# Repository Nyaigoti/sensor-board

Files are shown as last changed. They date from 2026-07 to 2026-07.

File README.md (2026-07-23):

# Custom IoT PCB with ESP32-C3-02 and TP4056 Li-ion Charger

This project involves the design and development of a custom PCB for an IoT application powered by the ESP32-C3-02 SoC. The board includes integrated power management features using the TP4056 Li-ion battery charger IC, enabling efficient and safe charging of a single-cell Li-ion battery.

### Key Features

- **Microcontroller**: ESP32-C3-02 SoC for Wi-Fi and BLE connectivity.
- **Power Management**: TP4056 IC for single-cell Li-ion battery charging with thermal regulation.
- **Battery Protection**: Integrated under-voltage lockout and trickle charging.
- **Sensors and Modules**:
  - BME280 for temperature, humidity, and pressure sensing.
  - Ambient light and sound sensors.
  - Mini SD card reader for data storage.
  - Flash memory for additional storage.
- **Display**: I2C OLED for real-time data visualization.
- **Power Inputs**:
  - USB-C connector for charging and data transfer.
  - LiPo battery connector with onboard charging circuitry.
- **Indicators**: LED indicators for charge status (charging and full).

### Design Highlights

1. **Power Supply Integration**:
   - USB-C provides power for both charging and system operation.
   - TP4056 handles battery charging and protection.
   - Power supplied to the ESP32-C3-02 is regulated for stability.

2. **Modular Architecture**:
   - Supports various sensors and peripherals for IoT applications.
   - Expandable via additional I2C devices.

3. **Safe and Efficient Charging**:
   - Programmable charging current using an external resistor.
   - Automatic charge termination and battery protection.

4. **Compact and Reliable Layout**:
   - Optimized PCB traces for minimal power loss.
   - Thermal management for the TP4056 and other components.

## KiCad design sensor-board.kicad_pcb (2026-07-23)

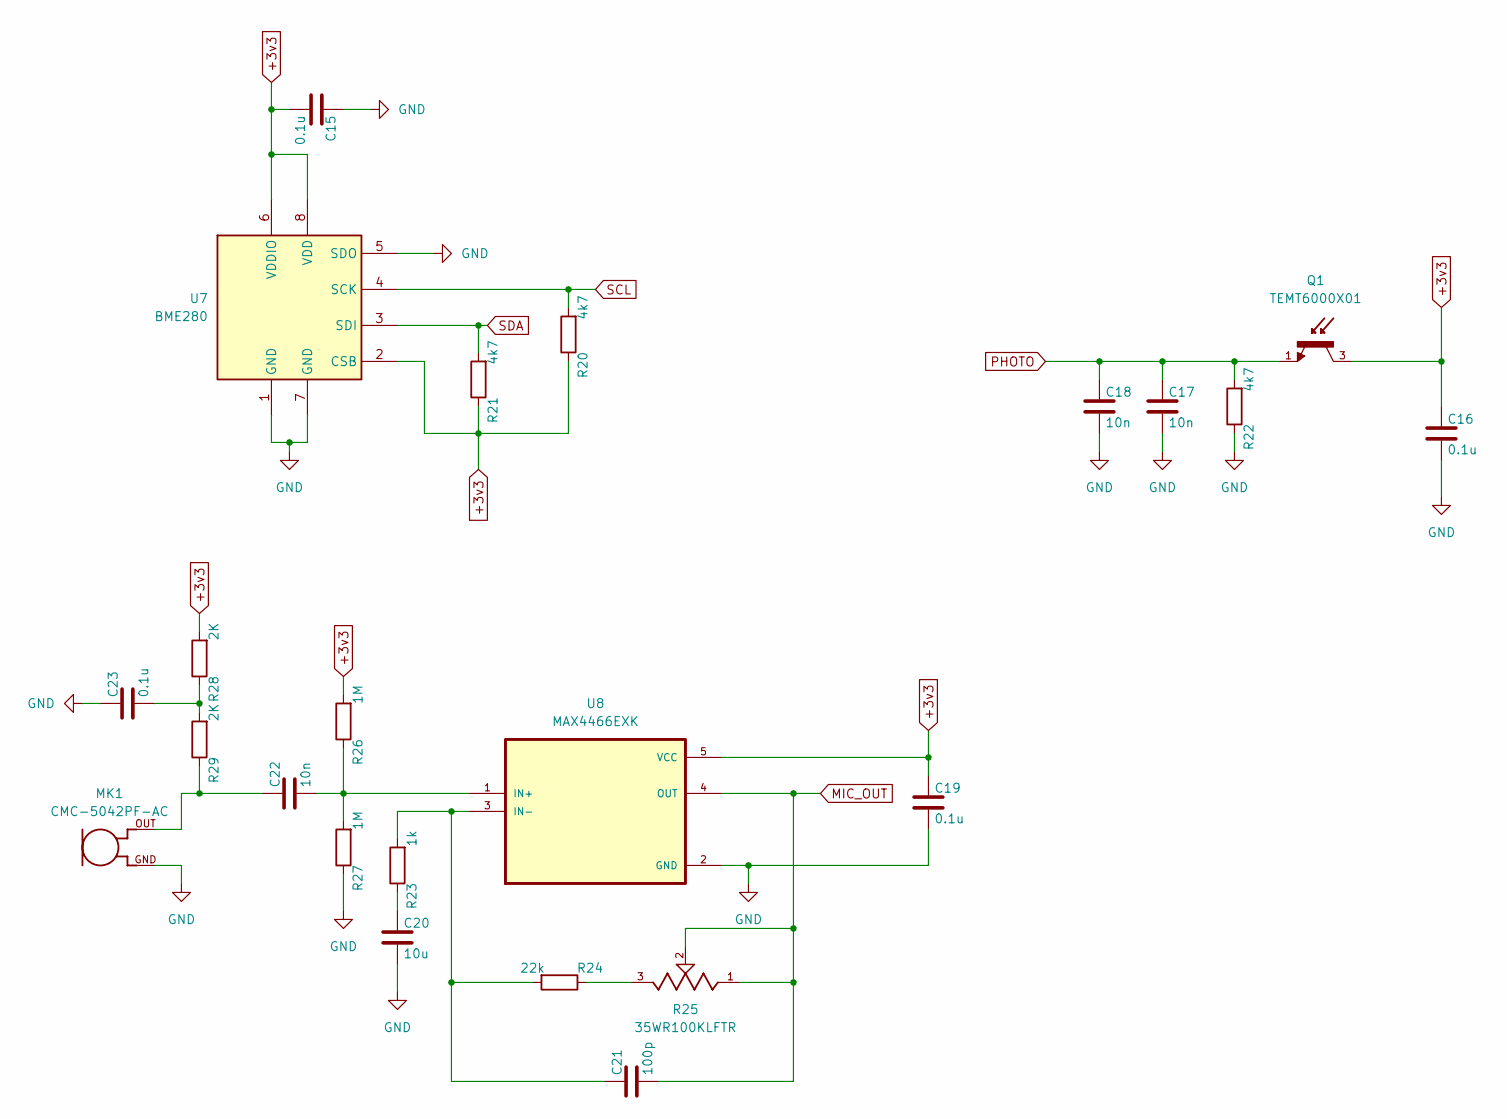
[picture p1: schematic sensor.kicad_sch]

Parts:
C15, C16, C19, C23: 0.1u; C_0805_2012Metric
C17, C18, C22: 10n; C_0805_2012Metric
C20: 10u; C_0805_2012Metric
C21: 100p; C_0805_2012Metric
MK1: CMC-5042PF-AC; CUI_CMC-5042PF-AC
Q1: TEMT6000X01; TRANS_TEMT6000X01; PARTREV 1.9
R20, R21, R22: 4k7; R_0805_2012Metric
R23: 1k; R_0805_2012Metric
R24: 22k; R_0805_2012Metric
R25: 35WR100KLFTR; TRIM_35WR100KLFTR; PARTREV D
R26, R27: 1M; R_0805_2012Metric
R28, R29: 2K; R_0805_2012Metric
U7: BME280; Bosch_LGA-8_2.5x2.5mm_P0.65mm_ClockwisePinNumbering
U8: MAX4466EXK; SOT65P210X110-5N

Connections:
+3v3: C15.2, C16.1, C19.1, Q1.3, R20.1, R21.1, R26.2, R28.2, U7.2 (CSB), U7.6 (VDDIO), U7.8 (VDD), U8.5 (VCC); also elsewhere on the board
GND: C15.1, C16.2, C17.2, C18.2, C19.2, C20.2, C23.1, MK1.GND, R22.1, R27.1, U7.1 (GND), U7.5 (SDO), U7.7 (GND), U8.2 (GND); also elsewhere on the board
MIC_OUT: C21.2, R25.1, R25.2, U8.4 (OUT); also elsewhere on the board
unnamed: C20.1, R23.1
unnamed: C22.1, MK1.OUT, R29.1
unnamed: C23.2, R28.1, R29.2
unnamed: R24.1, R25.3
unnamed: C22.2, R26.1, R27.2, U8.1 (IN+)
unnamed: C21.1, R23.2, R24.2, U8.3 (IN-)
PHOTO: C17.1, C18.1, Q1.1, R22.2; also elsewhere on the board
SCL: R20.2, U7.4 (SCK); also elsewhere on the board
SDA: R21.2, U7.3 (SDI); also elsewhere on the board

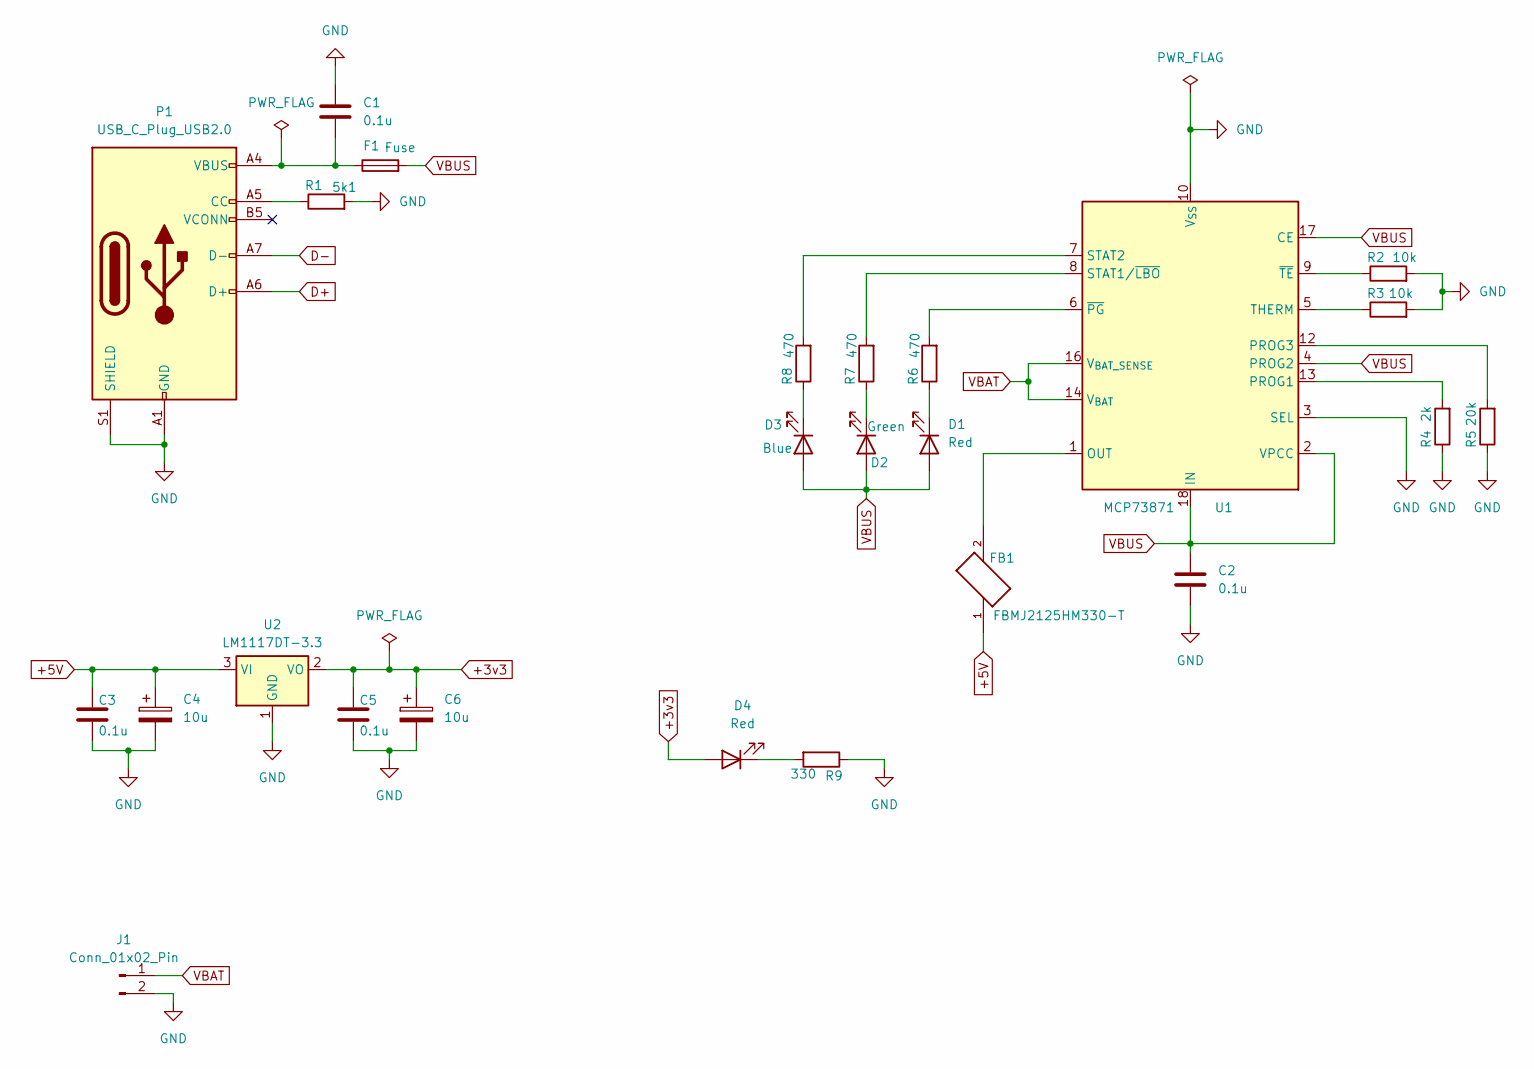
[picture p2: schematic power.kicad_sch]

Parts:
C1, C2, C3, C5: 0.1u; C_0805_2012Metric
C4, C6: 10u; C_0805_2012Metric
D1, D4: Red; LED_1206_3216Metric
D2: Green; LED_1206_3216Metric
D3: Blue; LED_1206_3216Metric
F1: Fuse; Fuse_1206_3216Metric
FB1: FBMJ2125HM330-T; BEADC2012X105N
J1: Conn_01x02_Pin; JST_EH_B2B-EH-A_1x02_P2.50mm_Vertical
P1: USB_C_Plug_USB2.0; USB_C_Receptacle_Amphenol_124019772112A
R1: 5k1; R_0805_2012Metric
R2, R3: 10k; R_0805_2012Metric
R4: 2k; R_0805_2012Metric
R5: 20k; R_0805_2012Metric
R6, R7, R8: 470; R_0805_2012Metric
R9: 330; R_0805_2012Metric
U1: MCP73871; QFN-20-1EP_4x4mm_P0.5mm_EP2.5x2.5mm
U2: LM1117DT-3.3; TO-252-3_TabPin2

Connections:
+3v3: C5.1, C6.1, D4.2 (A), U2.2 (VO); also elsewhere on the board
+5V: C3.1, C4.1, FB1.1, U2.3 (VI)
D+: P1.A6 (D+); also elsewhere on the board
D-: P1.A7 (D-); also elsewhere on the board
GND: C1.1, C2.2, C3.2, C4.2, C5.2, C6.2, J1.2, P1.A1 (GND), P1.A12 (GND), P1.B1 (GND), P1.B12 (GND), P1.S1 (SHIELD), R1.2, R2.2, R3.2, R4.1, R5.1, R9.1, U1.3 (SEL), U1.10 (V_{SS}), U1.11 (V_{SS}), U1.21 (V_{SS}), U2.1 (GND); also elsewhere on the board
unnamed: C1.2, F1.1, P1.A4 (VBUS), P1.A9 (VBUS), P1.B4 (VBUS), P1.B9 (VBUS)
unnamed: D1.1 (K), R6.1
unnamed: D2.1 (K), R7.1
unnamed: D3.1 (K), R8.1
unnamed: D4.1 (K), R9.2
unnamed: FB1.2, U1.1 (OUT), U1.20 (OUT)
unnamed: P1.A5 (CC), R1.1
unnamed: R4.2, U1.13 (PROG1)
unnamed: R5.2, U1.12 (PROG3)
unnamed: R7.2, U1.8 (STAT1/~LBO)
unnamed: R8.2, U1.7 (STAT2)
unnamed: R3.1, U1.5 (THERM)
unnamed: R6.2, U1.6 (~PG)
unnamed: R2.1, U1.9 (~TE)
VBAT: J1.1, U1.14 (V_{BAT}), U1.15 (V_{BAT}), U1.16 (V_{BAT_SENSE})
VBUS: C2.1, D1.2 (A), D2.2 (A), D3.2 (A), F1.2, U1.2 (VPCC), U1.4 (PROG2), U1.17 (CE), U1.18 (IN), U1.19 (IN); also elsewhere on the board

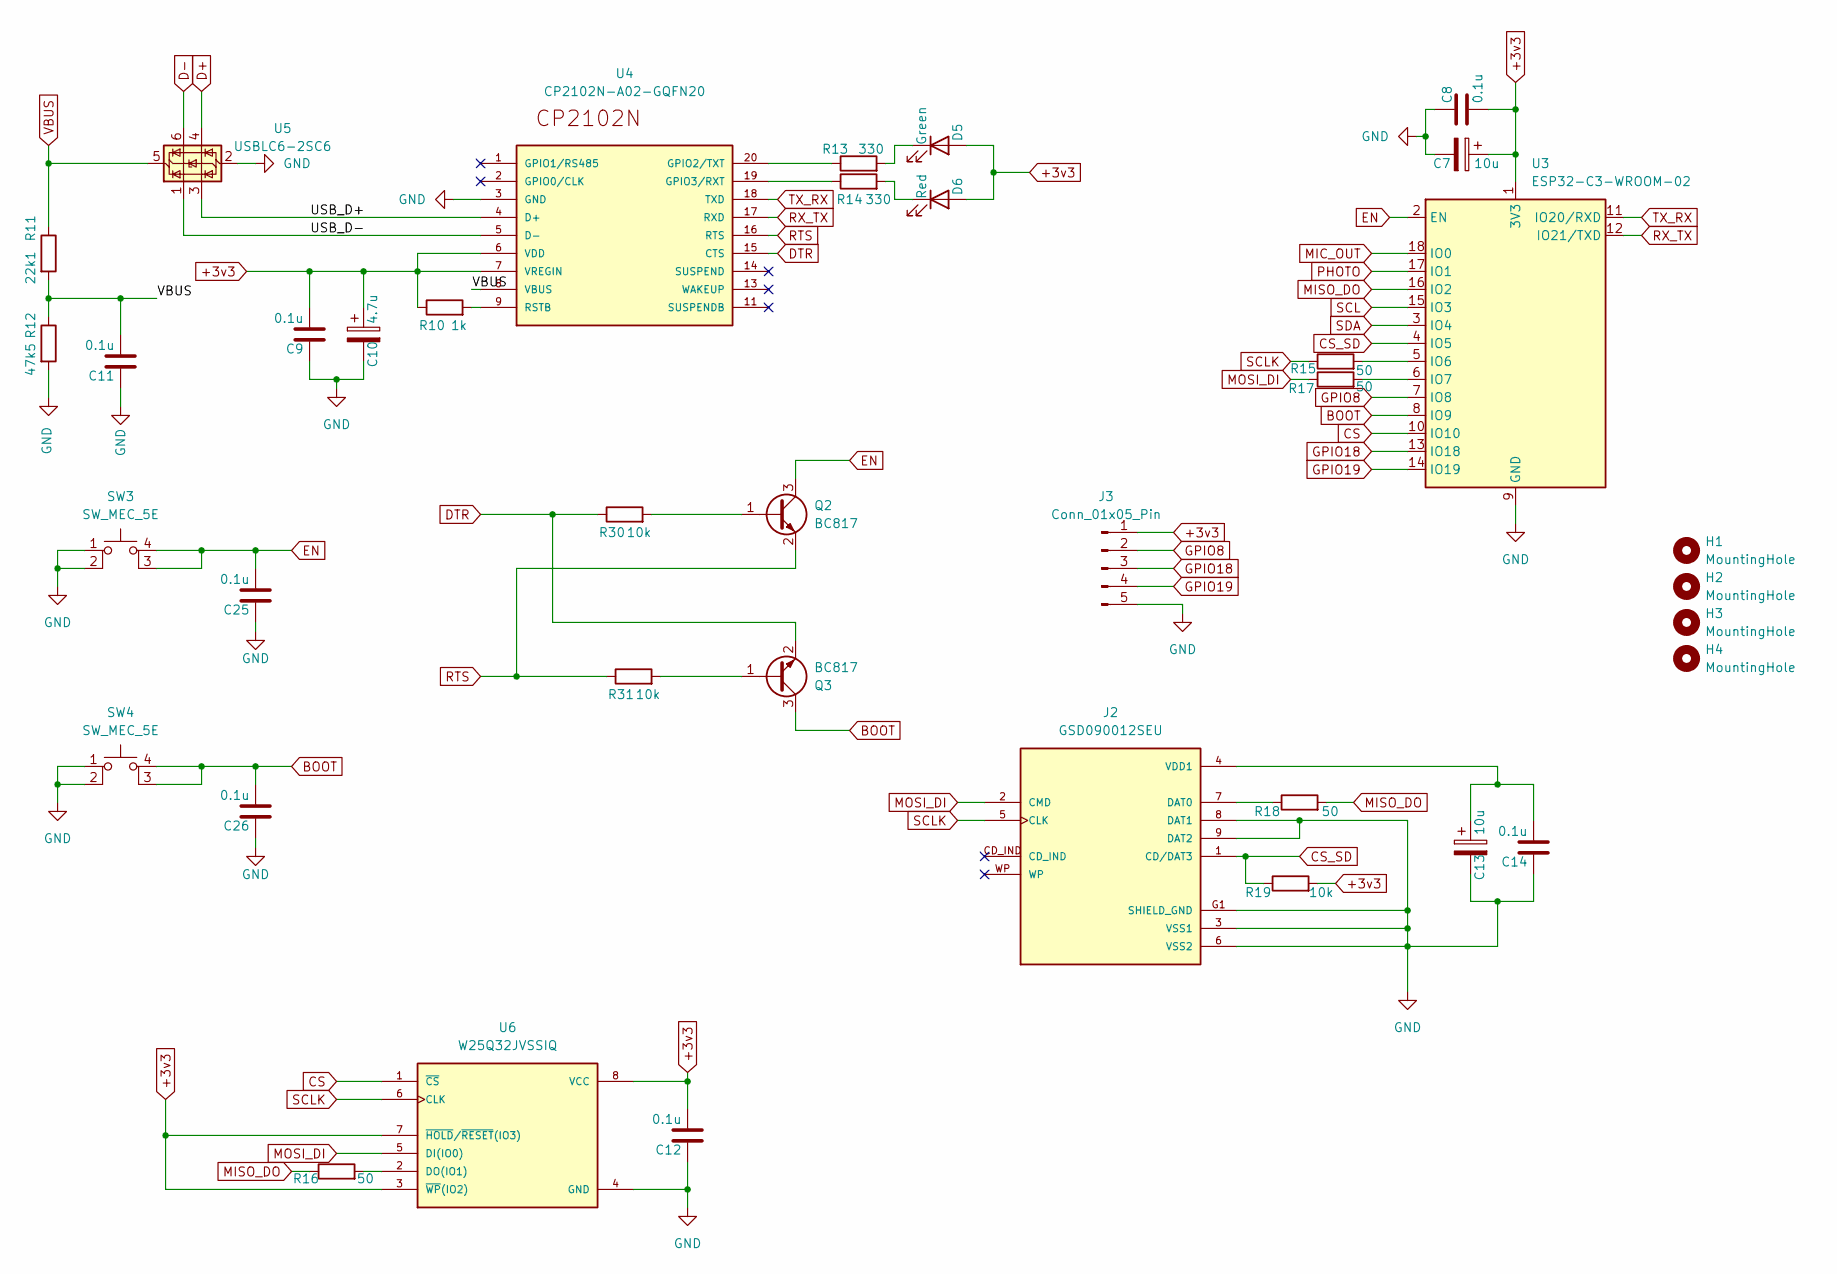
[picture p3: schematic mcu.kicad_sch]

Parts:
C7, C13: 10u; C_0805_2012Metric
C8, C9, C11, C12, C14, C25, C26: 0.1u; C_0805_2012Metric
C10: 4.7u; C_0805_2012Metric
D5: Green; LED_1206_3216Metric
D6: Red; LED_1206_3216Metric
H1, H2, H3, H4: MountingHole; MountingHole_2.2mm_M2_DIN965_Pad_TopBottom
J2: GSD090012SEU; AMPHENOL_GSD090012SEU; PARTREV E
J3: Conn_01x05_Pin; PinHeader_1x05_P2.54mm_Vertical_SMD_Pin1Left
Q2, Q3: BC817; SOT-23
R10: 1k; R_0805_2012Metric
R11: 22k1; R_0805_2012Metric
R12: 47k5; R_0805_2012Metric
R13, R14: 330; R_0805_2012Metric
R15, R16, R17, R18: 50; R_0805_2012Metric
R19, R30, R31: 10k; R_0805_2012Metric
SW3, SW4: SW_MEC_5E; SW_USLPT2819DT2TR
U3: ESP32-C3-WROOM-02
U4: CP2102N-A02-GQFN20; WFQFN-20
U5: USBLC6-2SC6; SOT-23-6
U6: W25Q32JVSSIQ; SOIC127P790X216-8N; M_PART_NUMBER W25QXX

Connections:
+3v3: C7.1, C8.2, C9.2, C10.1, C12.2, D5.2 (A), D6.2 (A), J3.1, R10.1, R19.2, U3.1 (3V3), U4.6 (VDD), U4.7 (VREGIN), U6.3 (~WP(IO2)), U6.7 (~HOLD/~RESET(IO3)), U6.8 (VCC); also elsewhere on the board
/mcu/USB_D+: U4.4 (D+), U5.3 (I/O2)
/mcu/USB_D-: U4.5 (D-), U5.1 (I/O1)
BOOT: C26.2, Q3.3 (C), SW4.3 (K), SW4.4 (A), U3.8 (IO9)
CS: U3.10 (IO10), U6.1 (~CS)
CS_SD: J2.1 (CD/DAT3), R19.1, U3.4 (IO5)
D+: U5.4 (I/O2); also elsewhere on the board
D-: U5.6 (I/O1); also elsewhere on the board
DTR: Q3.2 (E), R30.1, U4.15 (CTS)
EN: C25.2, Q2.3 (C), SW3.3 (K), SW3.4 (A), U3.2 (EN)
GND: C7.2, C8.1, C9.1, C10.2, C11.1, C12.1, C13.2, C14.1, C25.1, C26.1, J2.3 (VSS1), J2.6 (VSS2), J2.8 (DAT1), J2.9 (DAT2), J2.G1 (SHIELD_GND), J2.G2 (SHIELD_GND), J2.G3 (SHIELD_GND), J2.G4 (SHIELD_GND), J3.5, R12.2, SW3.1, SW3.2, SW4.1, SW4.2, U3.9 (GND), U3.19 (GND), U4.3 (GND), U4.12 (GND), U4.EXP (GND), U5.2 (GND), U6.4 (GND); also elsewhere on the board
GPIO8: J3.2, U3.7 (IO8)
GPIO18: J3.3, U3.13 (IO18)
GPIO19: J3.4, U3.14 (IO19)
MIC_OUT: U3.18 (IO0); also elsewhere on the board
MISO_DO: R16.1, R18.2, U3.16 (IO2)
MOSI_DI: J2.2 (CMD), R17.1, U6.5 (DI(IO0))
unnamed: D5.1 (K), R13.2
unnamed: D6.1 (K), R14.2
unnamed: J2.7 (DAT0), R18.1
unnamed: C13.1, C14.2, J2.4 (VDD1)
unnamed: Q2.1 (B), R30.2
unnamed: Q3.1 (B), R31.2
unnamed: R15.2, U3.5 (IO6)
unnamed: R17.2, U3.6 (IO7)
unnamed: R13.1, U4.20 (GPIO2/TXT)
unnamed: R14.1, U4.19 (GPIO3/RXT)
unnamed: R10.2, U4.9 (RSTB)
unnamed: R16.2, U6.2 (DO(IO1))
PHOTO: U3.17 (IO1); also elsewhere on the board
RTS: Q2.2 (E), R31.1, U4.16 (RTS)
RX_TX: U3.12 (IO21/TXD), U4.17 (RXD)
SCL: U3.15 (IO3); also elsewhere on the board
SCLK: J2.5 (CLK), R15.1, U6.6 (CLK)
SDA: U3.3 (IO4); also elsewhere on the board
TX_RX: U3.11 (IO20/RXD), U4.18 (TXD)
VBUS: C11.2, R11.1, R11.2, R12.1, U4.8 (VBUS), U5.5 (VBUS); also elsewhere on the board

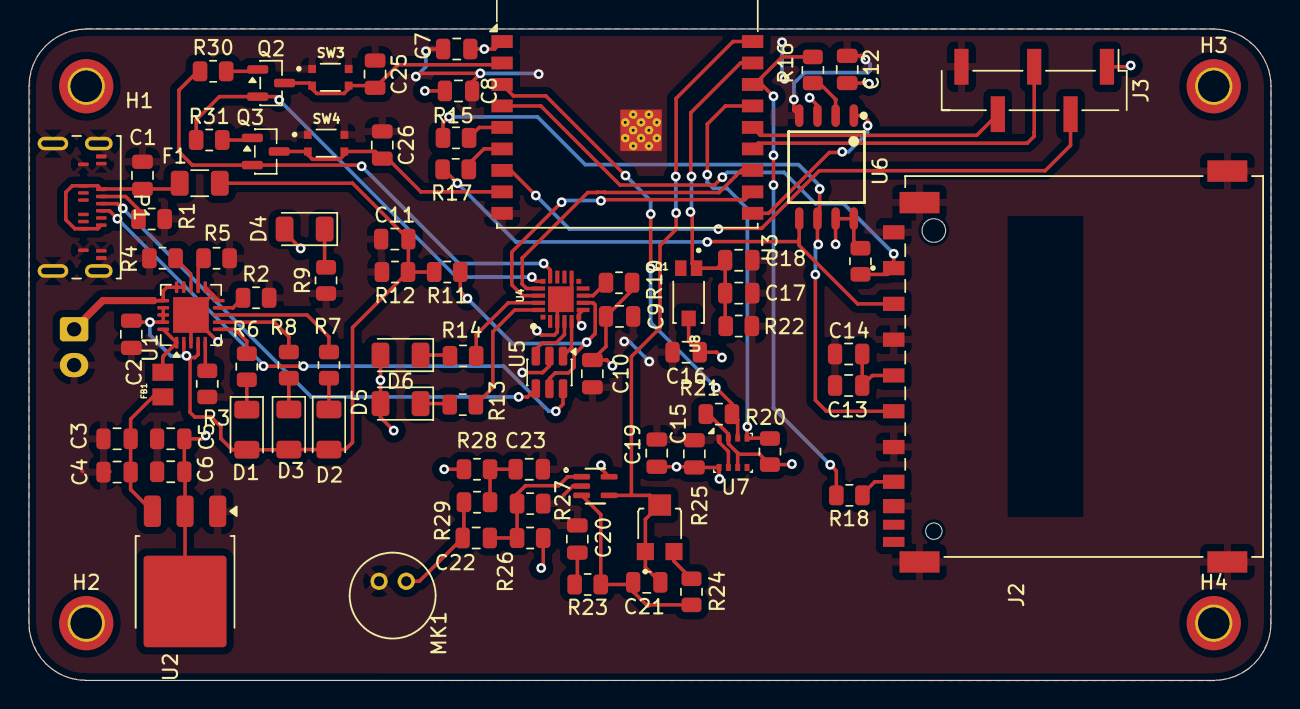
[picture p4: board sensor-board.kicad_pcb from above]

Board: 2 copper layers, 86.8 x 45.5 mm, 86 parts (1 on the bottom side), 59 nets.

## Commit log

2026-07-22 components arranged
    [mcu.kicad_sch, power.kicad_sch, sensor-board.kicad_pcb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]
2026-07-23 complete pcb
    [mcu.kicad_sch, power.kicad_sch, sensor-board.kicad_pcb]
